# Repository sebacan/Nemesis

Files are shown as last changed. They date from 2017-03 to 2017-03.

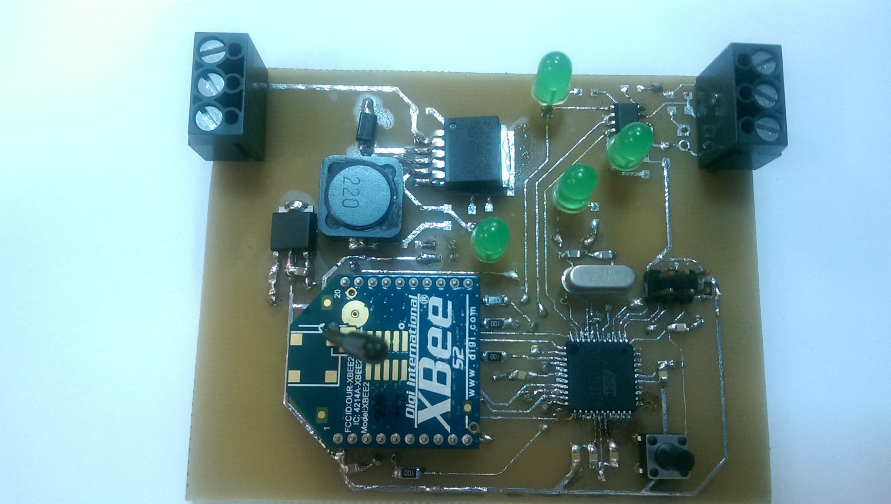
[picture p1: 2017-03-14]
xbee.jpg

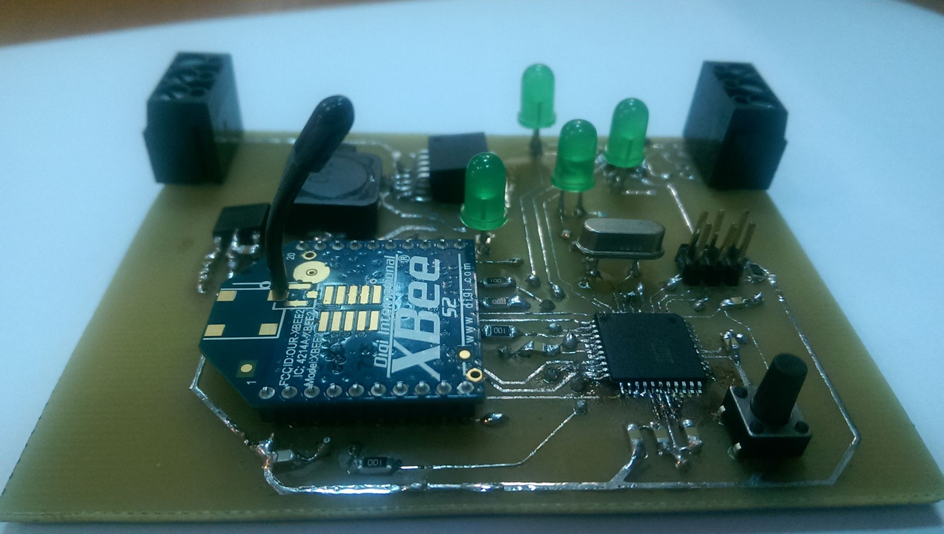
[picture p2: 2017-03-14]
xbee2.jpg

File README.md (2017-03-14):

# Nemesis

Este un proiect hardware,finalist in cadrul Innovation Labs Bucharest 2016. 

Proiect ce a participat si la Sesiunea de Comunicări Științifice Studențești 2016,Politehnica București. 

Se bazează pe colectarea datelor de interes dintr-o centrală/uzină/fabrică si trasmiterea acestora catre un centru de comandă. 

Ne folosim de modulele XBee/ZigBee pentru a forma o rețea mesh în care dispozitivele comunică între ele. 

Datele obținute sunt mai apoi centralizare si urmărite. 

Avantaje:
Ușurință în instalare și mentenanță.

Protocol de comunicație standardizat pe frecvențele 2.4 Ghz,433 Mhz.

Monitorizare în timp real.

Consum și costuri reduse.

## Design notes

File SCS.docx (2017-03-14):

NEMESIS
AGREGATOR DE PROTOCOALE PENTRU TRANSFERUL DATELOR

Autori: Brîndușescu Silvia[^1]

Cancel Sebastian[^2]

Miu Cătălina[^3]

Conducător științific: Asis. Drd. Ing. Cristian Dumitru Trancă

Prin această lucrare dorim să detaliem ideea noastră inovativă cu ajutorul căreia vrem să introducem un nou strandard în monitorizarea aparaturii și a proceselor din industria energetică.

Keywords: agregator de protocoale, costuri reduse, tehnologie Xbee, criptare

1. Introducere

Pe măsură ce timpul trece, oamenii pun tot mai mult preț pe dorința de a realiza totul cât mai rapid și cât mai eficient, fără pierderi și fără costuri prea ridicate. Când vine vorba de industria energetică, în spatele acestei dorințe există de fapt o necesitate întrucât defectarea sau funcționarea în afara parametrilor a unei singure instalații pentru o perioada relativ scurtă de timp produce pierderi și costuri ridicate, eficiență scazută și multe alte consecințe imediate. Dar oare ce s-ar întampla dacă toate instalațiile s-ar strica simultan? În mod cert ceva ce toata lumea vrea să evite.

2. Problema existentă

Sistemul de monitorizare folosit în momentul actual de majoritatea fabricilor constă în aparatură de dimensiuni destul de mari, dificil de folosit și pentru care este nevoie de oameni instruiți care să știe cum să utilizeze sistemul de monitorizare și cum să interpreteze datele furnizate de acestea.

Cea mai apropiată soluție existentă pe piață este un gateway al cărui cost ajunge undeva la 500€, soluție care nu este completă, ci în completarea căreia trebuie investit și în alte componente sau tehnologii.

3. Soluția noastră

Pentru a combate problemele menționate mai sus, am creat soluția de monitorizare si prevenire a defectiunilor în cadrul fabricilor, care unifică comunicarea între instalații. Prin proiectul nostru oferim un device compact ce, imediat ce este montat lângă centralele de măsură, le preia funcțiile. Interesant la modul în care realizăm transmiterea datelor este transferul wireless implementat cu ajutorul modulelor Xbee.

Am ales să folosim această tehnologie pentru puterea mare de transmitere a datelor, în medie de până la 2km, dar în funcție de modul și dacă este sau nu câmp deschis, există variații.Un alt avantaj al acestei tehnologii este posibilitatea criptării datelor,astfel furnizând un grad de siguranță ridicat.Cu ajutorul acestor dispozitive formăm o rețea mesh in care toate dispozitivele să comunice intre ele si sa nu depindă de o conexiune de tip master-slave,conexiune ce nu permitea monitorizarea tuturor centralelor de masură in acelasi timp.

Alimentarea dispozitivului o vom realiza de la reteaua locala,urmand sa coboram tensiunea la o valoare de 3.3 V pentru alimentarea microcontrolerului Atmega 324.Folosim aceste microcontroler datorita puterii mare de procesare si functiilor multiple.Cu ai sai 32 de pini,memoria de 32 kbytes si frecventa de pana la 20 MHz este solutia ideala pentru nevoile noastre.

Folosim un canal de comunicatie cu mufa RS485 pentru a putea comunica cu restul retelei.Standardul RS485 foloseste o comunicatie de tip half-duplex,informatia circulă intr-o singura direcție la un moment dat.

Prin intermediul acestui canal ne conectam la prezenta infrastructură a rețelei energetice si prelugram datele furnizate de centrala de masură.

Unificarea protocoalelor o vom realiza cu ajutorului programării software prin care vom detecta automat protocolul folosit in nodul respectiv,urmand să transmitem datele obținute prin wireless la alte device-uri din apropiere

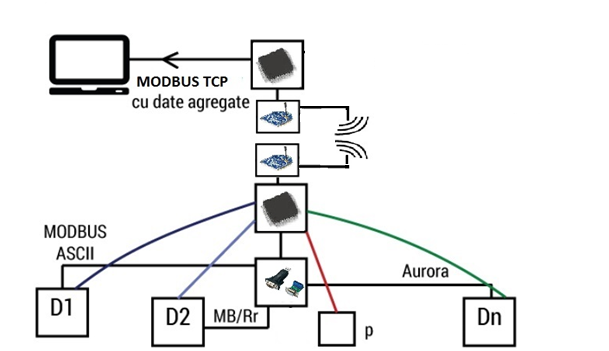
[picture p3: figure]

Figura 1.Schema hardware

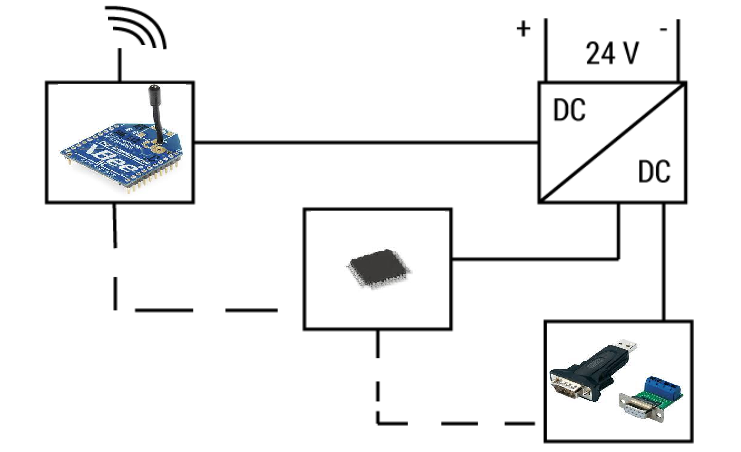
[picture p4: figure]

Figura 2.Schema principiului de funcționare

Comunicare

serială

4. Realizarea soluției hardware

În vederea realizării placuței hardware am realizat schematicul în Kicad care arată astfel:

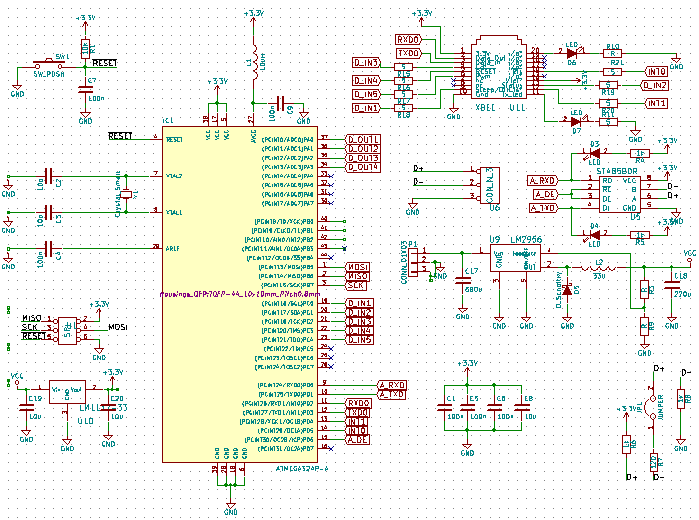
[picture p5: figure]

Figura 3.Realizarea solutiei hardware

Pasul următor a fost să realizăm board-ul. La acesta am realizat modificări de-a lungul timpului, reușind să facem soluția noastră și mai compactă, în final ajungând să arate astfel:

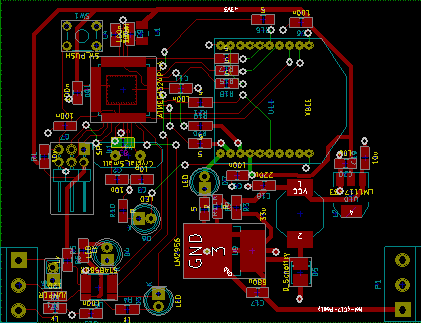
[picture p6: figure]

Figura 4.Circuitul imprimat

5. Avantaje

Printre diferențiatorii principali ai soluției noastre se numără:

- Putere de transmitere a datelor de până la 2 km line-of-sight
- Dimensiune compactă
- Prelucrarea datelor în timp real
6. Dificultăți tehnice

În realizarea proiectului am întampinat următoarele dificultăți, soluționate de-a lungul timpului:

- Realizarea unui produs compact
- Distanța mare de trasmisie
- Transfer în timp real a datelors
- Simplitate în utilizare
- Colectarea și prelucrarea datelor
7. Concluzii

Soluția propusă de noi vine ca o hartă fierbinte a parametrilor electrici, cu o serie de caracteristici inovative, menite să eficientizeze utilizarea resurselor, să reducă costurile, să faciliteze standardizarea și predictibilitatea transportului de date pentru echipamentele eterogene din industia energetică.


Figura 5.Placa de test

[^1] Anul 2, Facultatea de Automatică și Calculatoare, 323AC, e-mail: silvia.brindusescu@aut.pub.ro
[^2] Anul 2, Facultatea de Automatică și Calculatoare, 322AC, e-mail: sebastian.cancel@aut.pub.ro
[^3] Anul 2, Facultatea de Electronică, Telecomunicații și Tehnologia Informației, 421C

Universitatea POLITEHNICA din București Sesiunea de Comunicări Științifice Studențești 2016 Facultatea de Automatică și Calculatoare

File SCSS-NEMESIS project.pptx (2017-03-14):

## NEMESIS AGREGATOR DE PROTOCOALE PENTRU TRANSFERUL DATELOR

Sesiunea de Comunicări Științifice Studențești – Mai 2016

Autori

Conducători științifici

BRÎNDUȘESCU Silvia
CANCEL Sebastian
MIU Cătălina

## Cuprins

- Motivație & Obiectiv
- Arhitectura hardware
- Implementarea software
- Dificultățile tehnice întâlnite
- Rezultate obținute
- Concluzii

Sesiunea de Comunicări Științifice Studențești – Mai 2016

## Motivația & obiectivul

- Eficientizarea transferului de date între dispozitivele de măsură din sistemele energetice
- Gândirea și implementarea unei soluții eficiente

## Arhitectura sistemului

- Sursă de alimentare
- Bloc de alimentare
- Microcontroler Atmega 324
- Modul Xbee
- Canal de comunicație: RS485

Sesiunea de Comunicări Științifice Studențești – Mai 2016

## Arhitectura hardware


Sesiunea de Comunicări Științifice Studențești – Mai 2016

## Implementarea software

- Unificarea căilor de comunicații
- Identificarea automată a protocolului
- Fiabilitate
- Upload pe Cloud în timp real

Sesiunea de Comunicări Științifice Studențești – Mai 2016

## Dificultăți tehnice întâlnite

- Realizarea unui produs compact
- Distanța mare de trasmisie
- Transfer în timp real
- Simplitate în utilizare
- Colectarea și prelucrarea datelor

Sesiunea de Comunicări Științifice Studențești – Mai 2016

## Rezultate obținute

Putere mare de transmisie
Criptarea datelor
Dimensiuni reduse
Prelucrare în timp real
Cost de aproximativ 400$
Componente low-power
Modularitate

Sesiunea de Comunicări Științifice Studențești – Mai 2016

## Concluzii

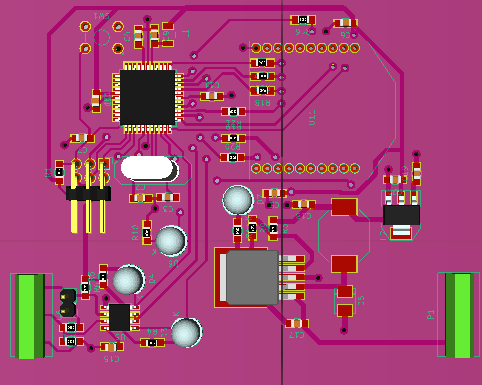
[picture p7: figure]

Sesiunea de Comunicări Științifice Studențești – Mai 2016

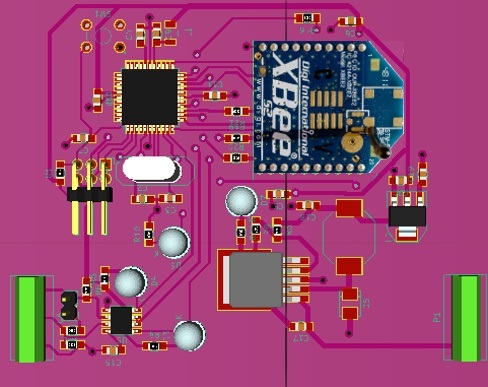
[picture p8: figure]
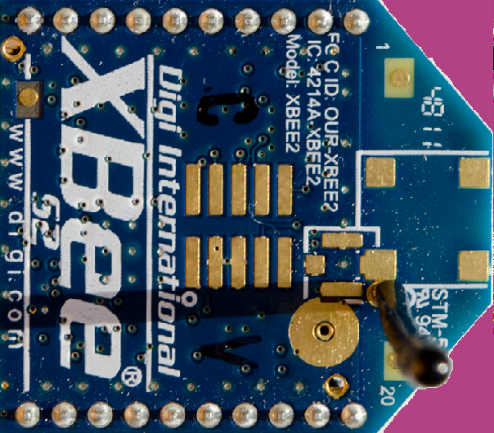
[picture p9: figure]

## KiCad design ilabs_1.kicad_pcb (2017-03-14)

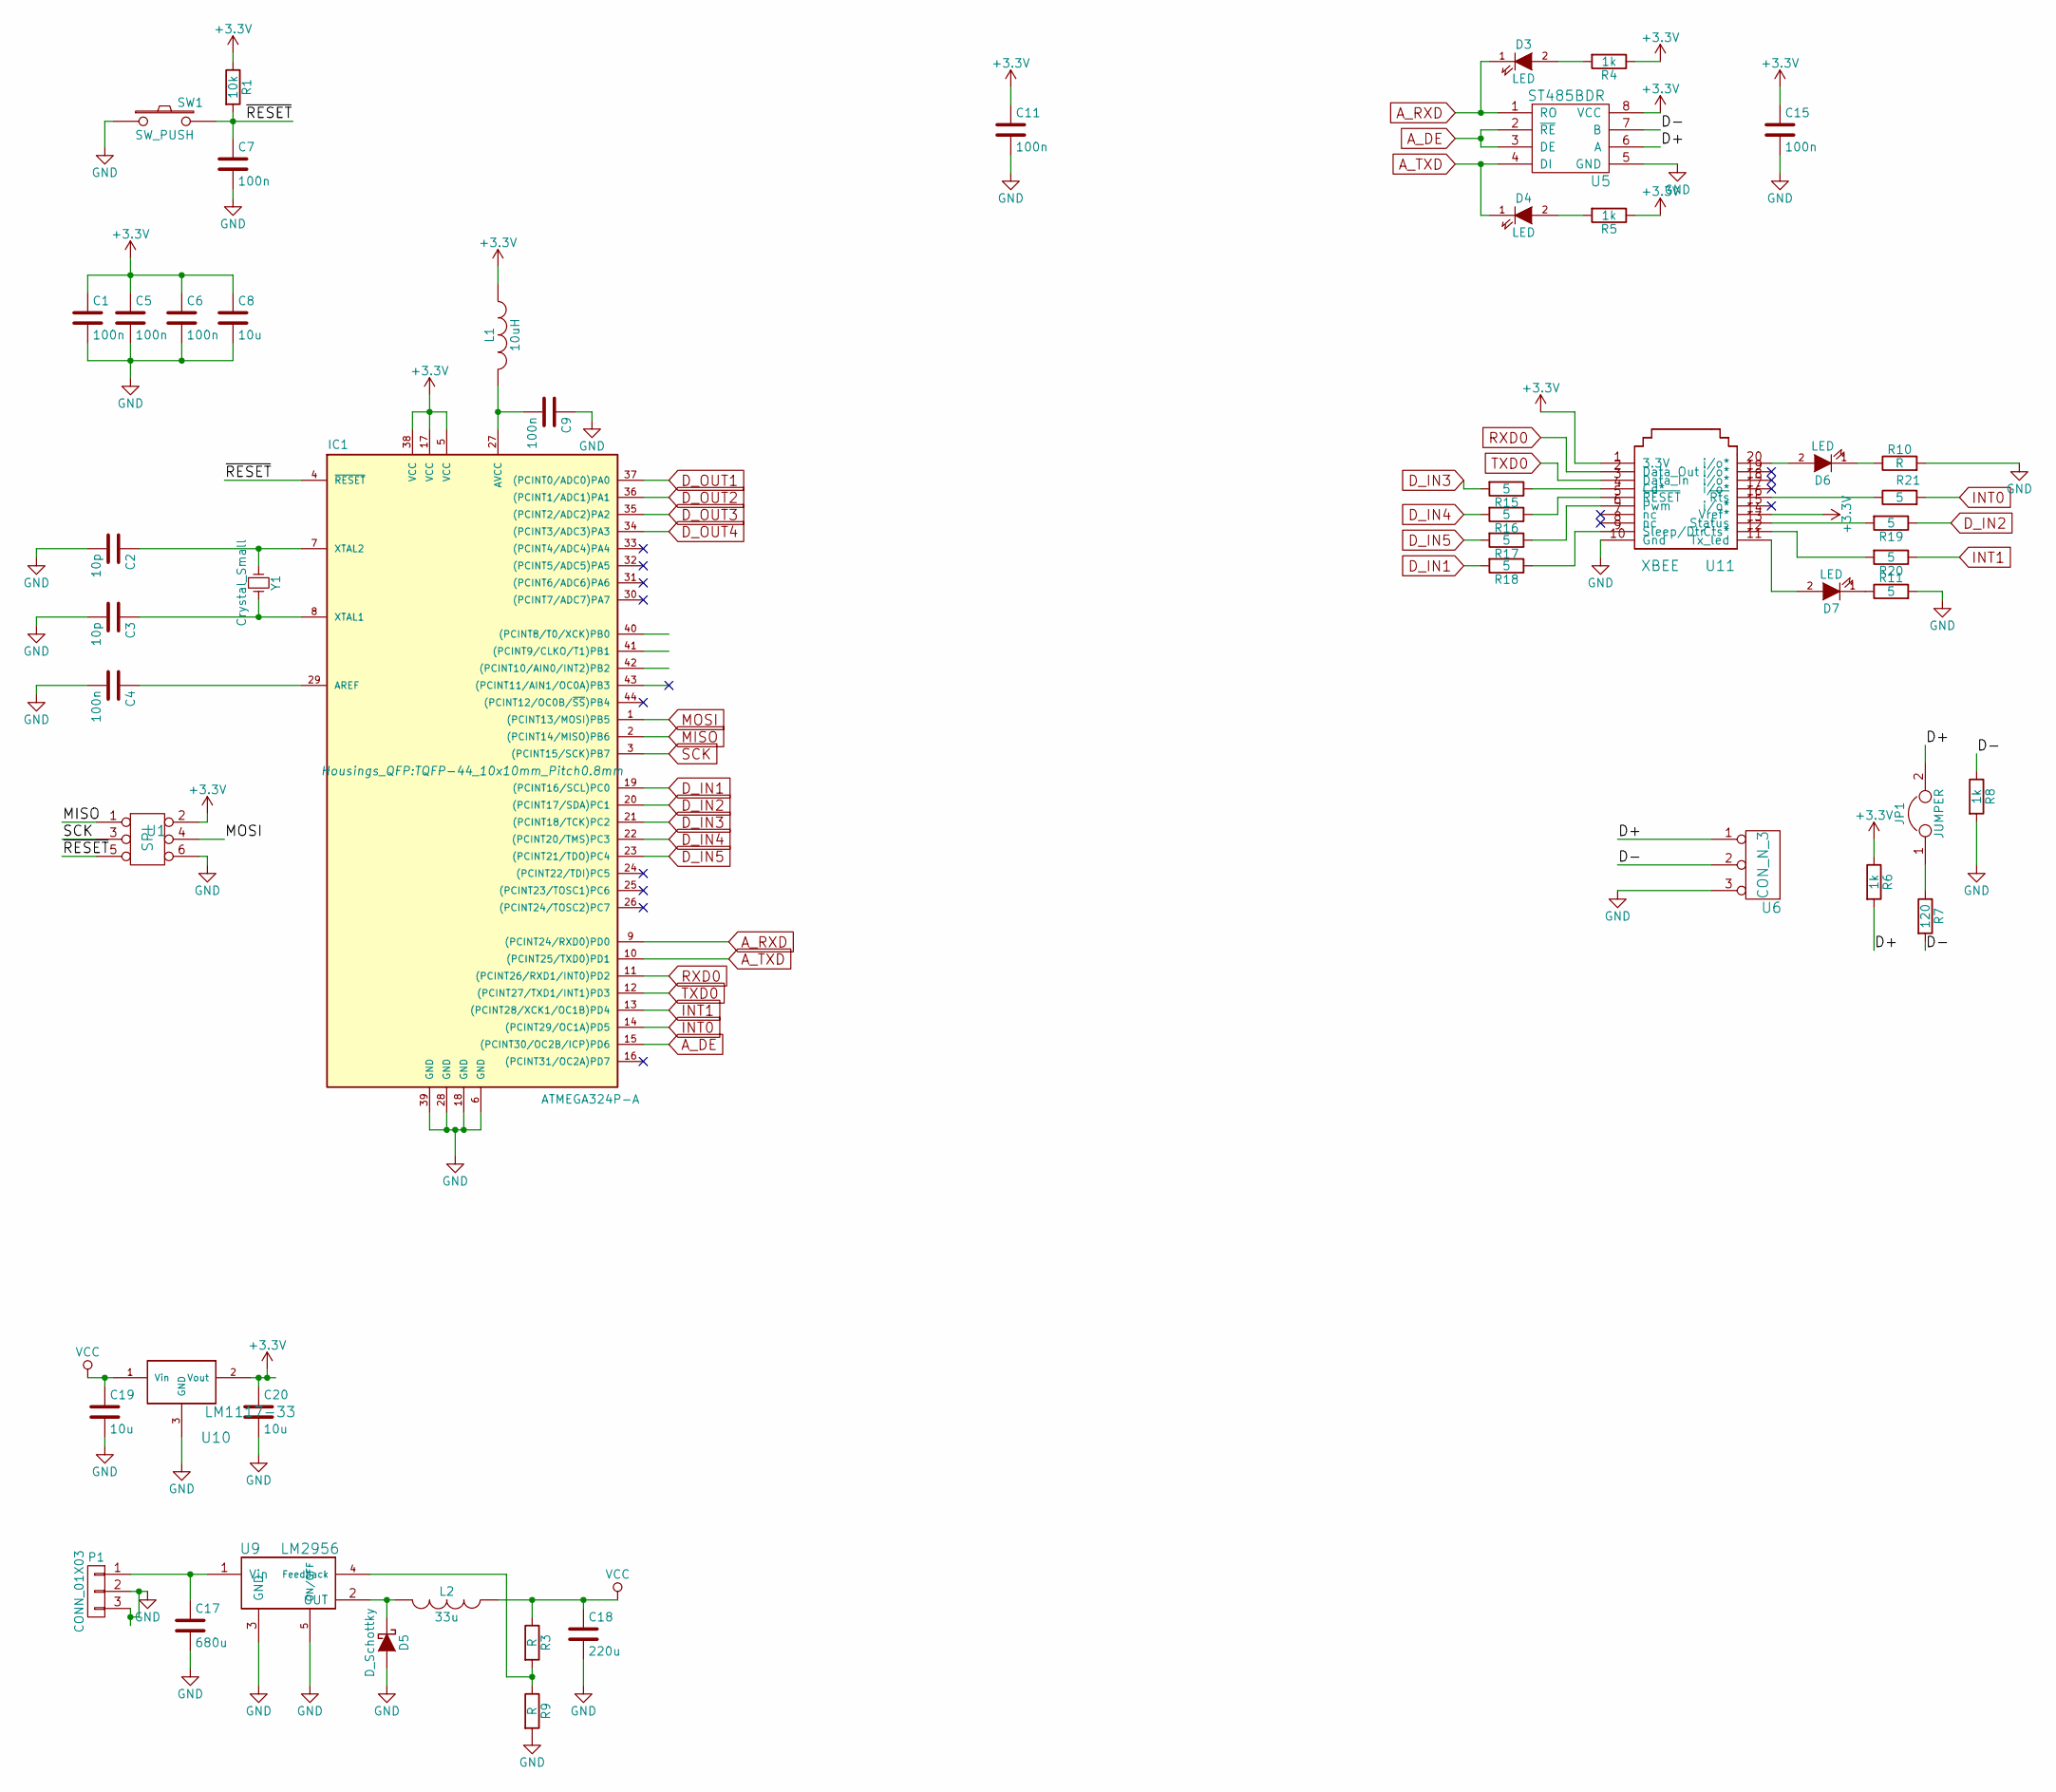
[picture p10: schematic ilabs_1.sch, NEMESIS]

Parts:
C1, C4, C5, C6, C7, C9, C11, C15: 100n; C_0805_HandSoldering
C2, C3: 10p; C_0805_HandSoldering
C8, C19, C20: 10u; C_0805_HandSoldering
C17: 680u; C_0805_HandSoldering
C18: 220u; C_0805_HandSoldering
D3, D4, D6, D7: LED; LED-5MM
D5: D_Schottky; DO-214AB_Handsoldering
IC1: ATMEGA324P-A; TQFP-44_10x10mm_Pitch0.8mm
JP1: JUMPER; Pin_Header_Angled_1x02
L1: 10uH; Neosid_Inductor_SM-NE30_SMD1210
L2: 33u; Neosid_Inductor_Ms95
P1: CONN_01X03; bornier3
R1: 10k; R_0805_HandSoldering
R3, R9, R10: R; R_0805_HandSoldering
R4, R5, R6, R8: 1k; R_0805_HandSoldering
R7: 120; R_0805_HandSoldering
R11, R15, R16, R17, R18, R19, R20, R21: 5; R_0805_HandSoldering
SW1: SW_PUSH
U1: SPI; Pin_Header_Angled_2x03
U5: ST485BDR; SOIC-8_3.9x4.9mm_Pitch1.27mm
U6: CON_N_3; bornier3
U9: LM2956; TO-263-5Lead
U10: LM1117-33; SOT-223
U11: XBEE
Y1: Crystal_Small; HC-18UV

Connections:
+3V3: C1.1, C5.1, C6.1, C8.1, C11.1, C15.1, C20.1, IC1.5 (VCC), IC1.17 (VCC), IC1.38 (VCC), L1.1, R1.1, R4.1, R5.1, R6.1, U1.2, U5.8 (VCC), U10.2 (Vout), U11.1 (3.3V), U11.14 (Vref*)
/D+: JP1.2, R6.2, U5.6 (A), U6.1
/D-: R7.2, R8.1, U5.7 (B), U6.2
/~RESET: C7.1, IC1.4 (~RESET), R1.2, SW1.2, U1.5
A_DE: IC1.15 ((PCINT30/OC2B/ICP)PD6), U5.2 (~RE), U5.3 (DE)
A_RXD: D3.1 (K), IC1.9 ((PCINT24/RXD0)PD0), U5.1 (RO)
A_TXD: D4.1 (K), IC1.10 ((PCINT25/TXD0)PD1), U5.4 (DI)
D_IN1: IC1.19 ((PCINT16/SCL)PC0), R18.2
D_IN2: IC1.20 ((PCINT17/SDA)PC1), R19.1
D_IN3: IC1.21 ((PCINT18/TCK)PC2), R15.2
D_IN4: IC1.22 ((PCINT20/TMS)PC3), R16.2
D_IN5: IC1.23 ((PCINT21/TDO)PC4), R17.2
D_OUT1: IC1.37 ((PCINT0/ADC0)PA0)
D_OUT2: IC1.36 ((PCINT1/ADC1)PA1)
D_OUT3: IC1.35 ((PCINT2/ADC2)PA2)
D_OUT4: IC1.34 ((PCINT3/ADC3)PA3)
GND: C1.2, C2.2, C3.2, C4.2, C5.2, C6.2, C7.2, C8.2, C9.1, C11.2, C15.2, C17.2, C18.2, C19.2, C20.2, D5.2 (A), IC1.6 (GND), IC1.18 (GND), IC1.28 (GND), IC1.39 (GND), P1.2, P1.3, R8.2, R9.2, R10.2, R11.2, SW1.1, U1.6, U5.5 (GND), U6.3, U9.3 (GND), U9.5 (ON/OFF), U10.3 (GND), U11.10 (Gnd)
INT0: IC1.14 ((PCINT29/OC1A)PD5), R21.2
INT1: IC1.13 ((PCINT28/XCK1/OC1B)PD4), R20.1
MISO: IC1.2 ((PCINT14/MISO)PB6), U1.1
MOSI: IC1.1 ((PCINT13/MOSI)PB5), U1.4
unnamed: C2.1, IC1.7 (XTAL2), Y1.1
unnamed: C3.1, IC1.8 (XTAL1), Y1.2
unnamed: C4.1, IC1.29 (AREF)
unnamed: C9.2, IC1.27 (AVCC), L1.2
unnamed: C17.1, P1.1, U9.1 (Vin)
unnamed: D3.2 (A), R4.2
unnamed: D4.2 (A), R5.2
unnamed: D5.1 (K), L2.2, U9.2 (OUT)
unnamed: D6.1 (K), R10.1
unnamed: D6.2 (A), U11.20 (i/o*)
unnamed: D7.1 (K), R11.1
unnamed: D7.2 (A), U11.11 (Tx_led)
unnamed: JP1.1, R7.1
unnamed: R3.2, R9.1, U9.4 (Feedback)
unnamed: R15.1, U11.4 (Cd*)
unnamed: R16.1, U11.5 (~RESET)
unnamed: R17.1, U11.6 (Pwm)
unnamed: R18.1, U11.9 (Sleep/Dtr)
unnamed: R19.2, U11.13 (Status)
unnamed: R20.2, U11.12 (Cts*)
unnamed: R21.1, U11.16 (~Rts)
RXD0: IC1.11 ((PCINT26/RXD1/INT0)PD2), U11.2 (Data_Out)
SCK: IC1.3 ((PCINT15/SCK)PB7), U1.3
TXD0: IC1.12 ((PCINT27/TXD1/INT1)PD3), U11.3 (Data_In)
VCC: C18.1, C19.1, L2.1, R3.1, U10.1 (Vin)

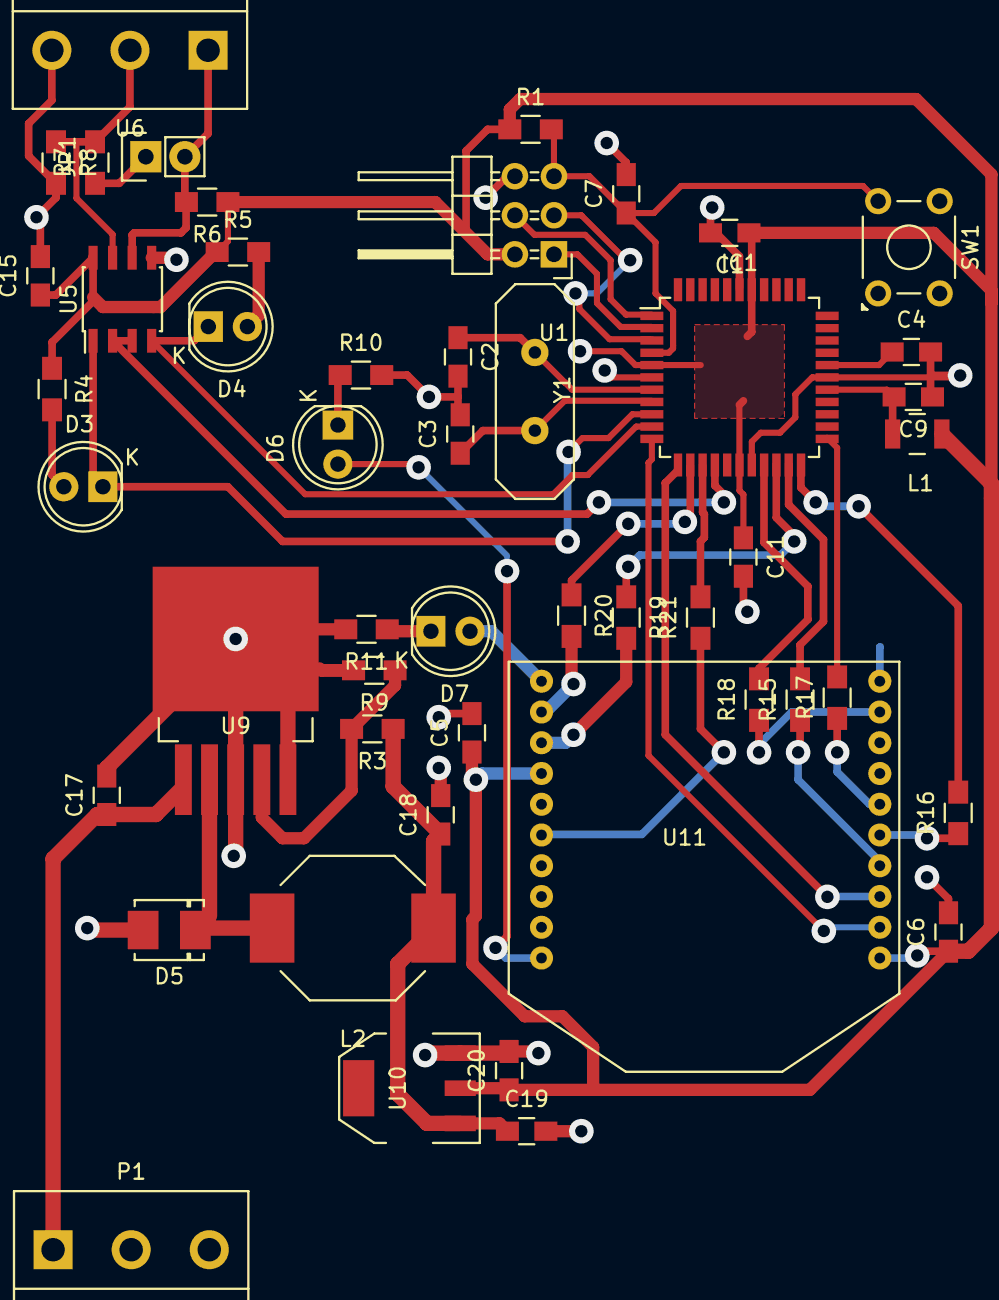
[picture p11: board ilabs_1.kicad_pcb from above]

Board: 2 copper layers, 50 parts (1 on the bottom side), 42 nets.
